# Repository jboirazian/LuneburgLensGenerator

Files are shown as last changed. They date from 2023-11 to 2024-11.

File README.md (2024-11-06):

# Luneburg Lens Genarator

Python script for generating a Luneburg Lens programatically without the use of 3D modeling software based on the [Pymesh](https://github.com/PyMesh/PyMesh) platform

This program was developed for the subject "Medidas electronicas 2" for the UTN FRBA university in the year 2023.

For more information check our [white paper](https://github.com/jboirazian/LuneburgLensGenerator/blob/main/white-paper.pdf)

> [!NOTE]  
> This project is a precursor to [LuneForge](https://github.com/jboirazian/LuneForge)

## How to run it:

You will need [Docker](https://www.docker.com/) for this project.

clone the project , then :

    docker build -t luneburg-gen .

Then:

    docker run -v "$(pwd)":/app -w /app luneburg-gen

# Example of use:

We designed and builded a Luneburg Lens that operated in Band X (8-12 Ghz). We also wanted to use a commercial FDM 3D printer and PLA filament.

Our design parameters were the following:

    k=100 ## Scale factor
    radius = 1.0 ## Unscaled sphere radious
    square_hole_size = 0.2 ## Square hole size lenght
    resolution = 4 ## sphere resolution (4 is fine , for highier resolution increase it , keeping in mind that it will increase the .stl model size)
    step = diameter/16 ## square holes resolution
    hole_variability=(((abs(x*x)+abs(y*y)))+square_hole_size*3)/3

If you want to print this lens , keep in mind to use 100% infill when printing the lens.

You can find this lens on the [Releases section](https://github.com/jboirazian/LuneburgLensGenerator/releases/tag/v1)

## Our results:

Before printing we runned some simulations in CST Studio and confirmed that there was a substantial increase in gain and directivity with our Lens

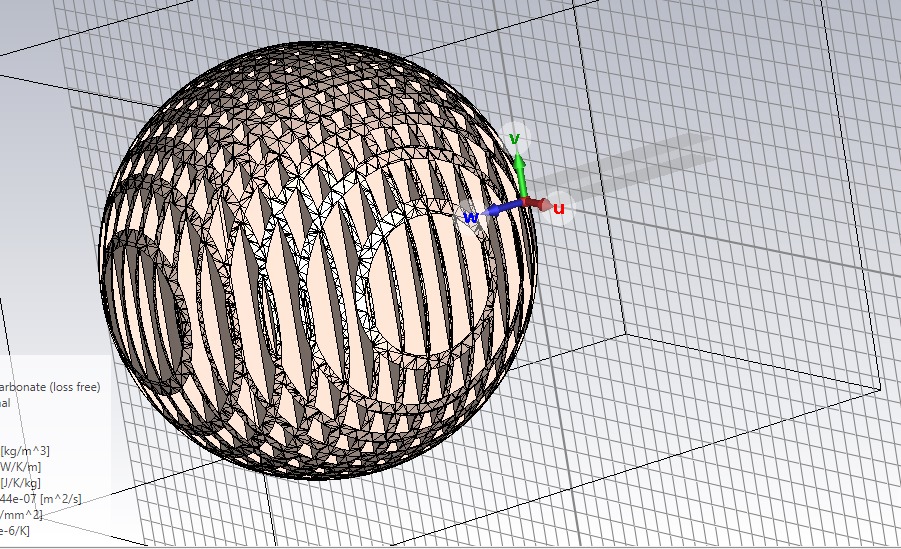
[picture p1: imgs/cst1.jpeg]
cst1


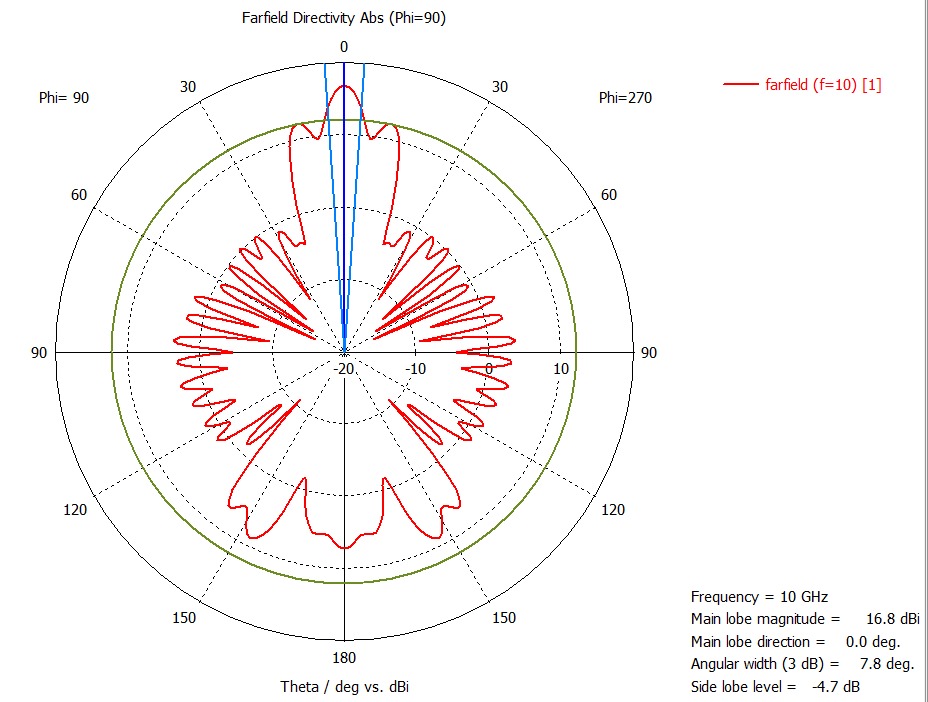
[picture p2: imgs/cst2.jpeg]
cst2


We were able to run multiple tests in our setup with VNA and 2 horn antennas (one as a transmitter and one as a reciver) and we successfully confimed our Simulations in CST Studio. We dramatically saw a gain in the S12 and S21 parameters of 6 db and more directivity in the beam

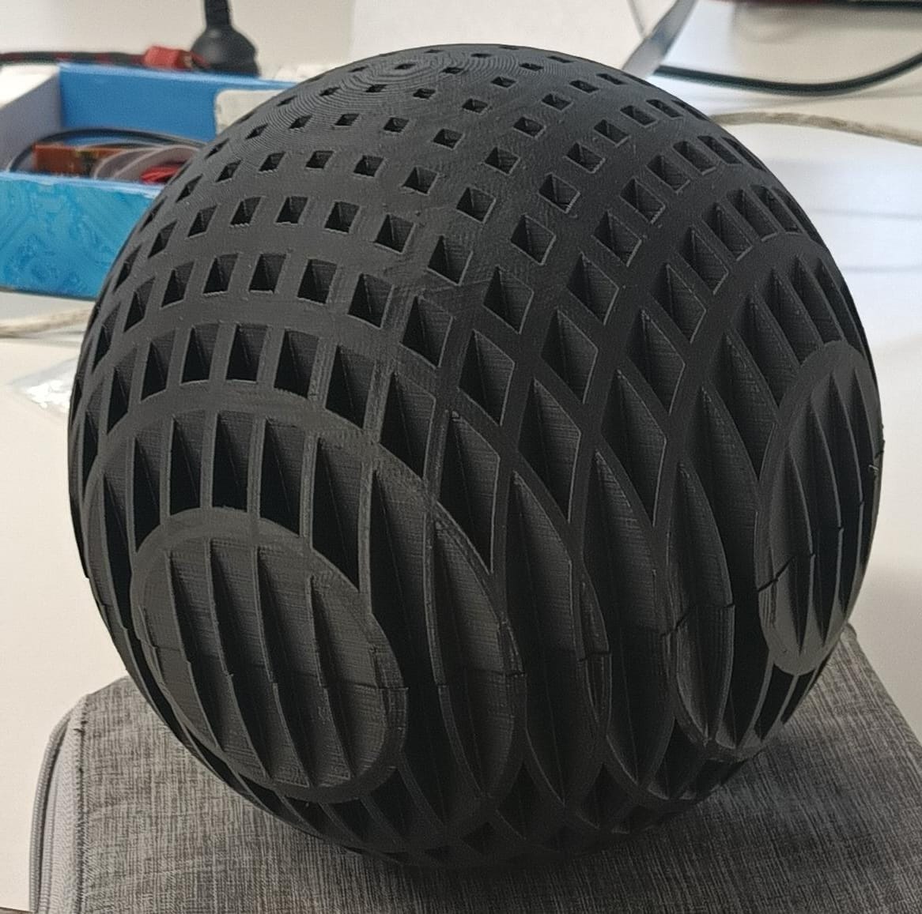
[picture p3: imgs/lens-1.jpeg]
lens1

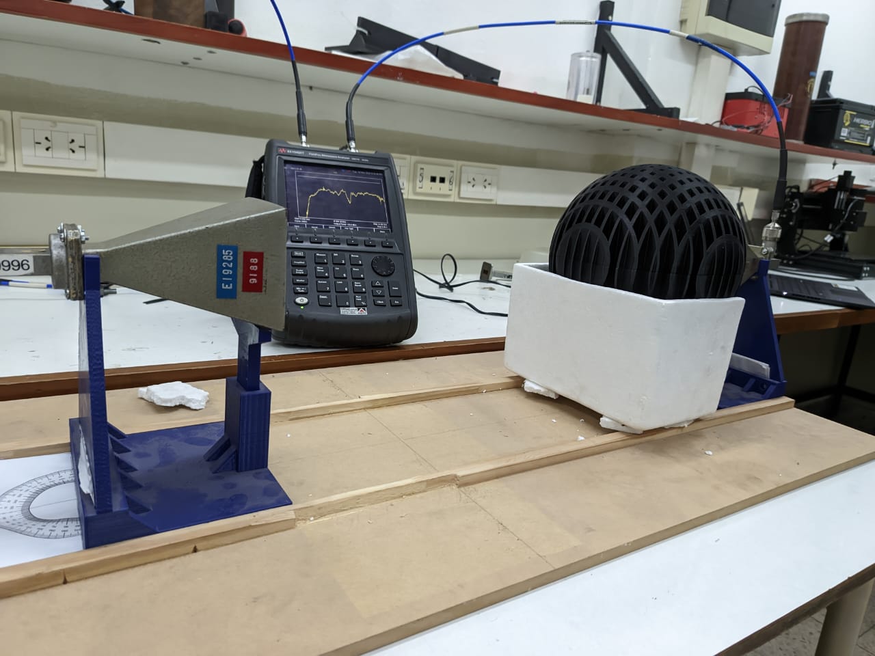
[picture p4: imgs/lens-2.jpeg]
lens2

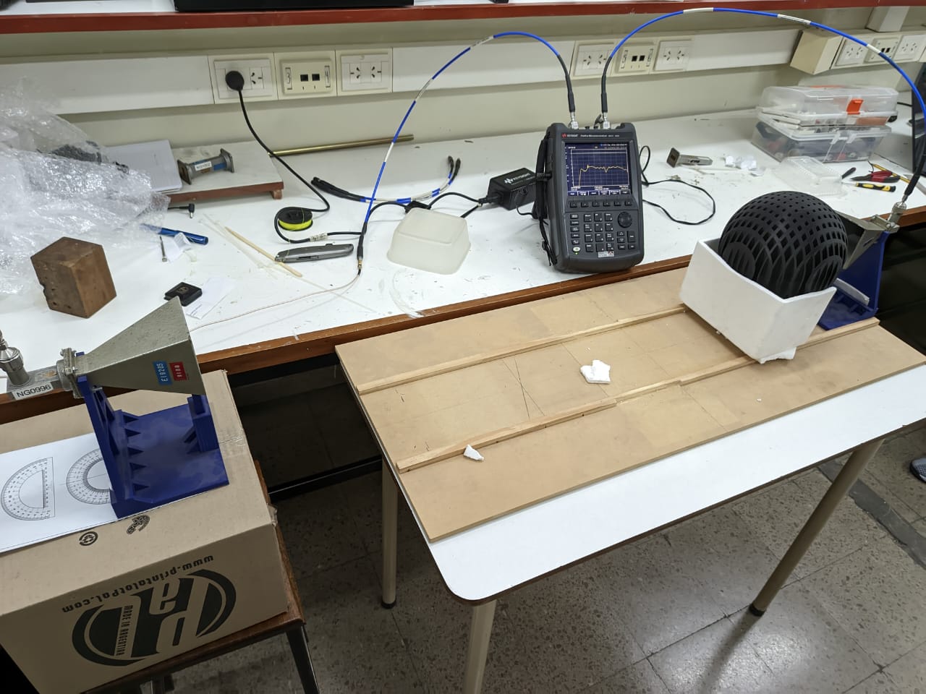
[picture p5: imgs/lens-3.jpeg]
lens3

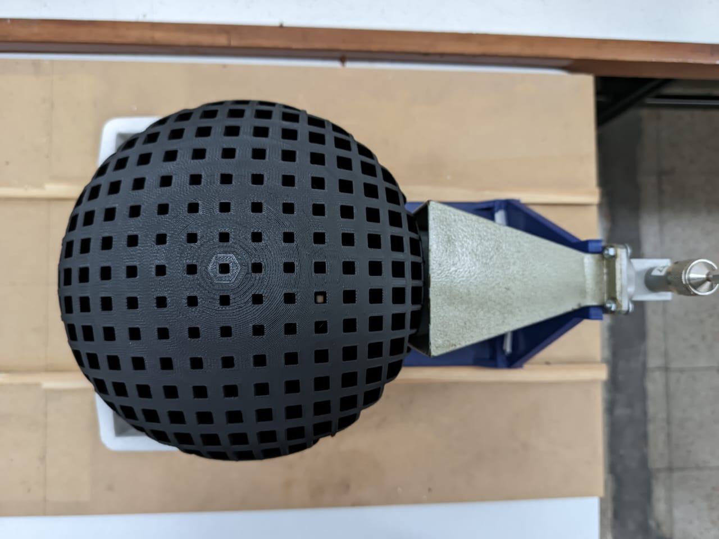
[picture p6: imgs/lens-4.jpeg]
lens4


# Contact information:

+ [Juan Agustín Boirazian](https://www.linkedin.com/in/juan-boirazian/)

+ [Juan Ignacio Falabella](https://www.linkedin.com/in/juan-ignacio-falabella-8ba659161/)

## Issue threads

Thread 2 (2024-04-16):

ModuleNotFoundError: No module named 'modules'

grafbobrovsky, 2024-04-16:
2024-04-16 14:50:42 Traceback (most recent call last):
2024-04-16 14:50:42   File "Luneburg.py", line 1, in <module>
2024-04-16 14:50:42     import modules.stl_generator_pymesh as stl_gen
2024-04-16 14:50:42 ModuleNotFoundError: No module named 'modules'

Any ideas how to resolve this? Thanks in advance.

jboirazian, 2024-05-03:
Hi! sorry fotr the late replay . Did you runned it like this using docker ?

docker build -t luneburg-gen .

then

docker run -v "$(pwd)":/app -w /app luneburg-gen

Closed 2024-05-07.
